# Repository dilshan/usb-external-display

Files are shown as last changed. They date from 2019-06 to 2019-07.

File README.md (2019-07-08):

# USB seven segment display module

USB Display Module

This seven segment display module is specifically designed to work with *POS* systems and banking applications. Initially, this module is developed to work with PC based systems, and later it was modified to work with other platforms and applications.

To simplify the communication interface this unit emulates a *COM* port in the host terminal. Because of this feature, this module can work with many systems without having any additional device driver(s).

This display module is designed around *STM32F103CB* MCU. The firmware of this display unit operates with most of the *STM32F103C* series MCUs, which including *STM32F103C8T6* based Blue Pill board. 

This is [certified](https://certification.oshwa.org/lk000003.html) open source hardware project. All the design files, [documentation](https://github.com/dilshan/usb-external-display/wiki), firmware source code are available to download at the [project source repository](https://github.com/dilshan/usb-external-display/releases). All the content of this project are distributed under the terms of the following license:

-   Hardware License: [CC BY 4.0](https://creativecommons.org/licenses/by/4.0/)
-   Software License: [MIT](https://github.com/dilshan/usb-external-display/blob/master/LICENSE)
-   Documentation License: [CC BY 4.0](https://creativecommons.org/licenses/by/4.0/)

OSHW-LK000003 (https://certification.oshwa.org/lk000003.html)

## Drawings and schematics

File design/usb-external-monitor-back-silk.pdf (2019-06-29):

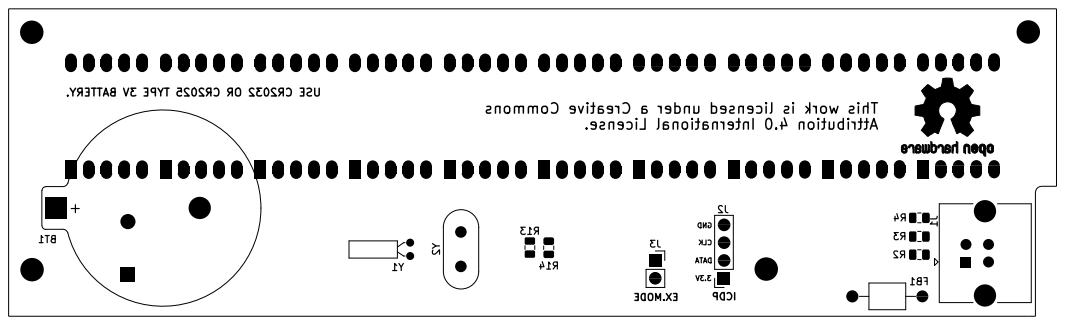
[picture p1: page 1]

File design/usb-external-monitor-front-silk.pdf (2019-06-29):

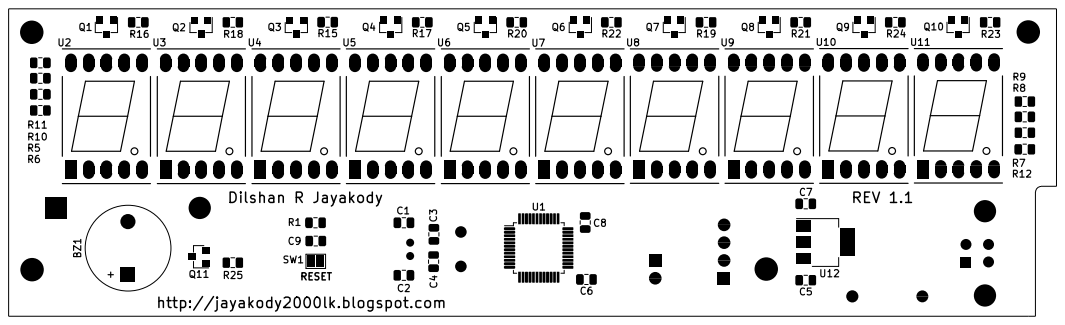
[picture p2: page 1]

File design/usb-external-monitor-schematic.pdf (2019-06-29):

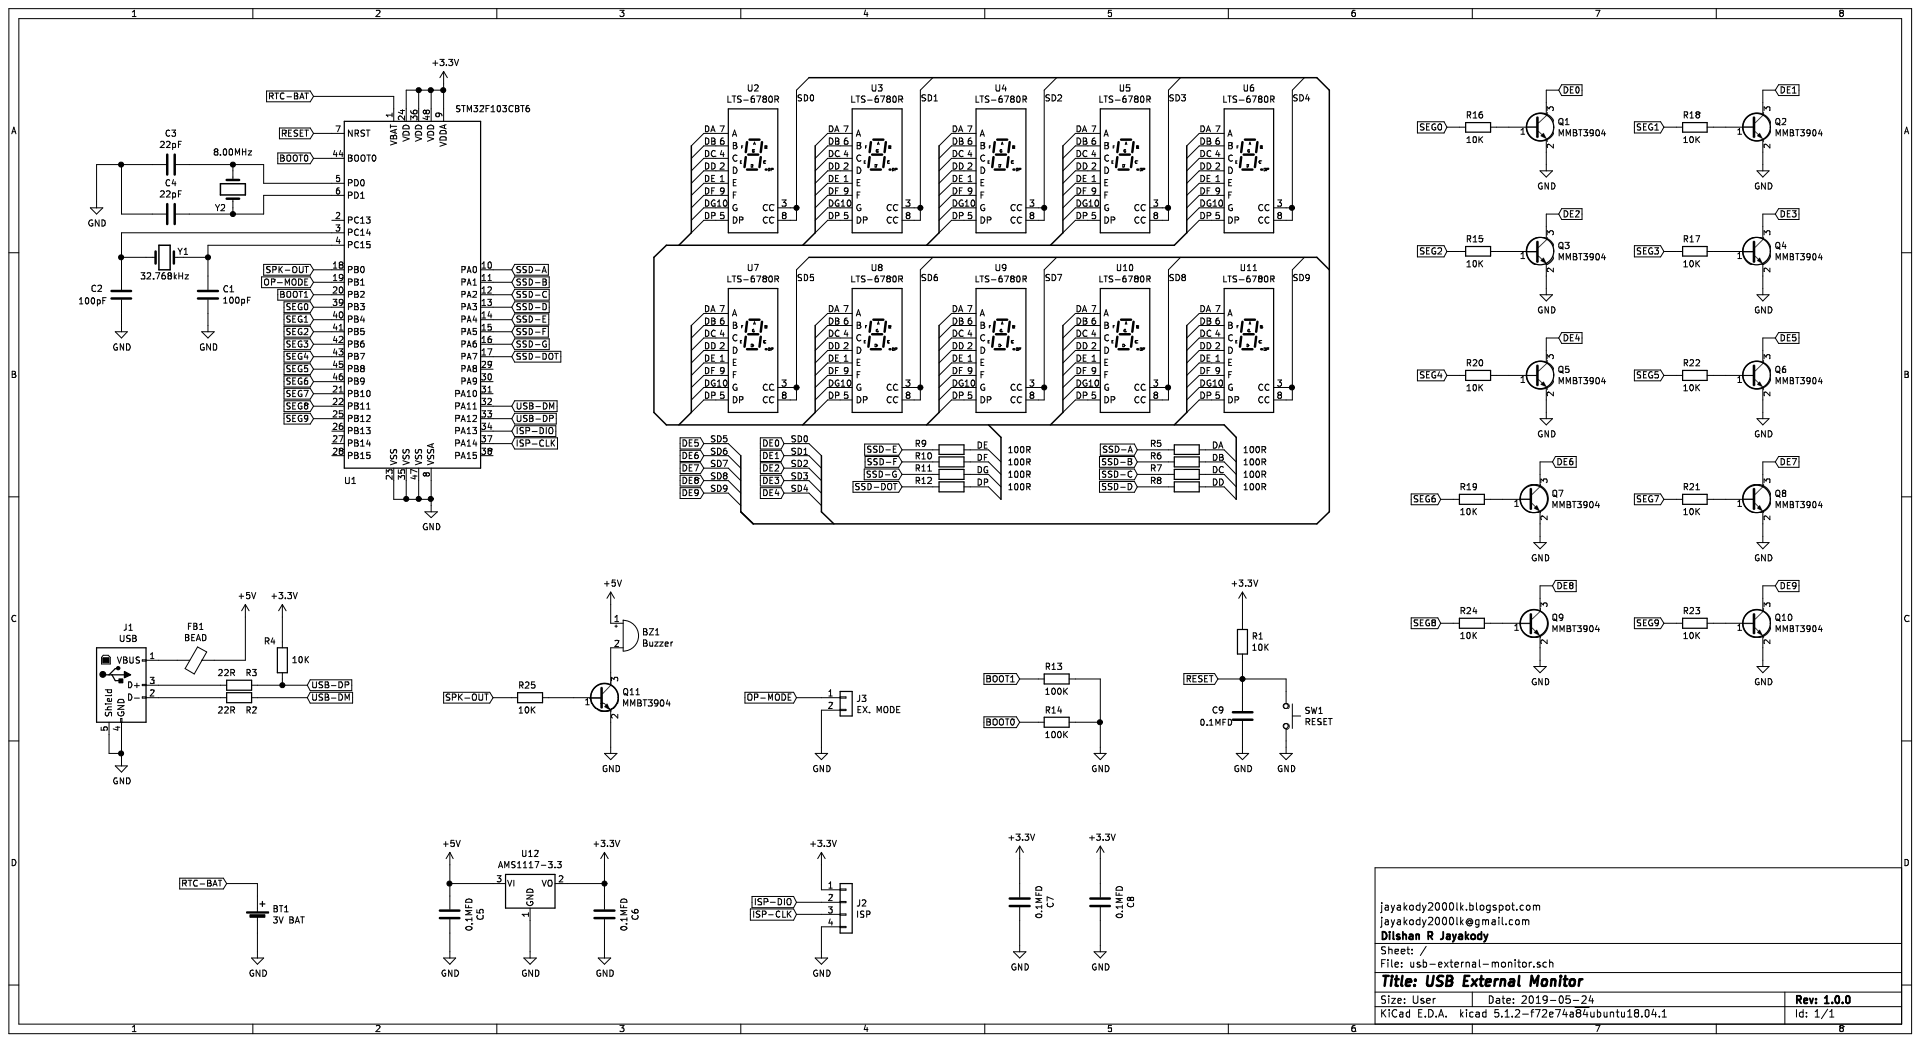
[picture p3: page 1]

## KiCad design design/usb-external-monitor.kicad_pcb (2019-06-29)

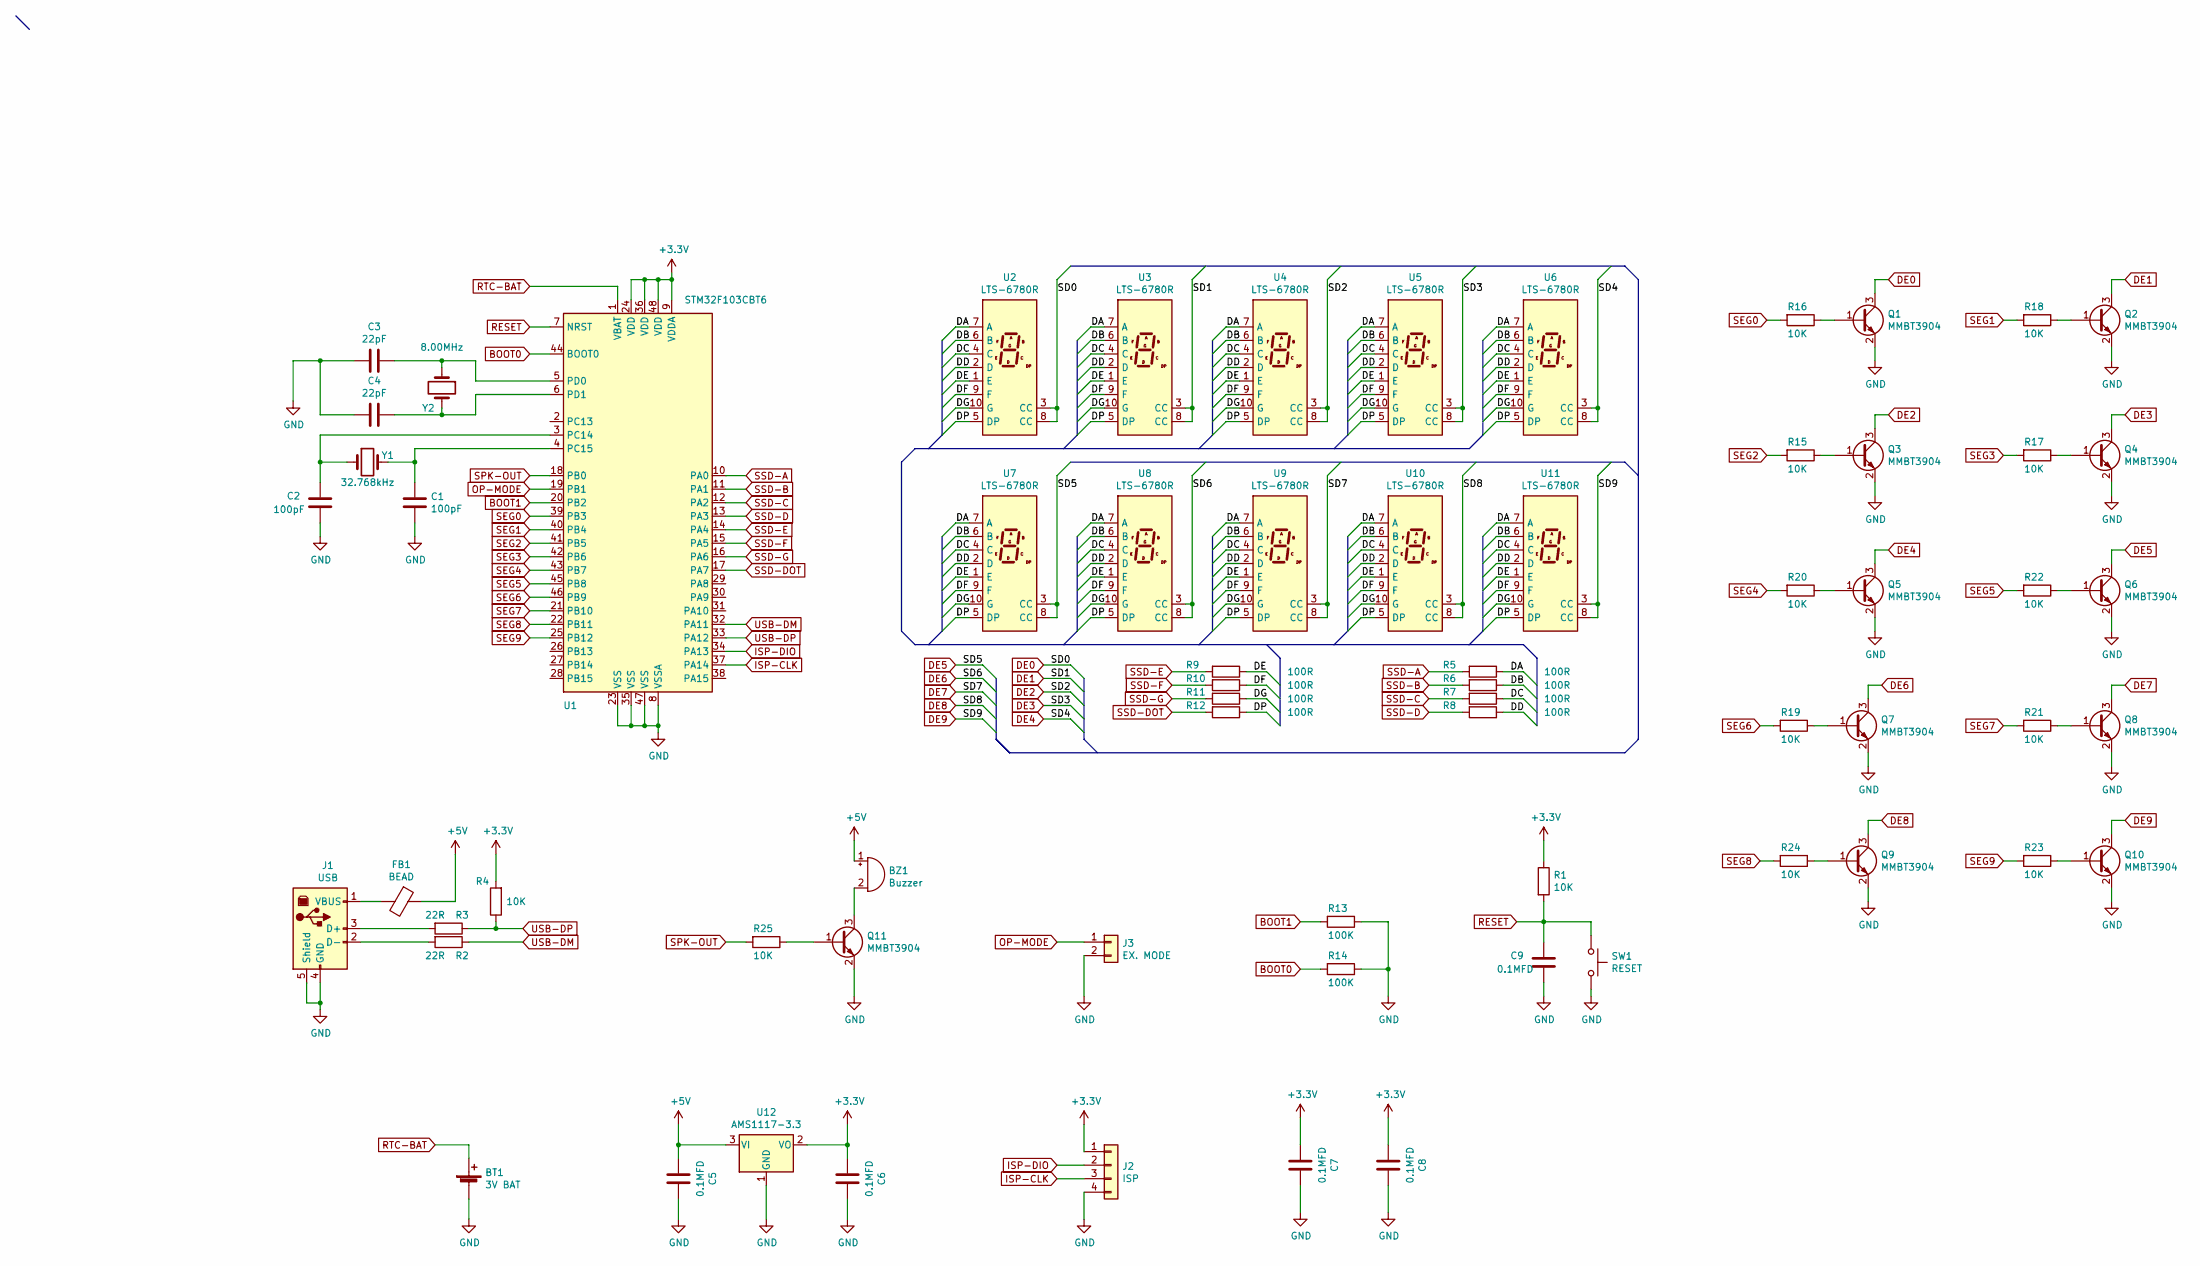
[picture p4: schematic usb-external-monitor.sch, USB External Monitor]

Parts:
BT1: 3V BAT; BatteryHolder_Keystone_105_1x2430
BZ1: Buzzer; Buzzer_12x9.5RM7.6
C1, C2: 100pF; C_0805_2012Metric
C3, C4: 22pF; C_0805_2012Metric
C5, C6, C7, C8, C9: 0.1MFD; C_0805_2012Metric
FB1: BEAD; L_Axial_L5.0mm_D3.6mm_P10.00mm_Horizontal_Murata_BL01RN1A2A2
J1: USB; USB_B_TE_5787834_Vertical
J2: ISP; PinHeader_1x04_P2.54mm_Vertical
J3: EX. MODE; PinHeader_1x02_P2.54mm_Vertical
Q1, Q2, Q3, Q4, Q5, Q6, Q7, Q8, Q9, Q10, Q11: MMBT3904; SOT-23
R1, R4, R15, R16, R17, R18, R19, R20, R21, R22, R23, R24, R25: 10K; R_0805_2012Metric
R2, R3: 22R; R_0805_2012Metric
R5, R6, R7, R8, R9, R10, R11, R12: 100R; R_0805_2012Metric
R13, R14: 100K; R_0805_2012Metric
SW1: RESET; SolderJumper-2_P1.3mm_Open_Pad1.0x1.5mm
U1: STM32F103CBT6; LQFP-48_7x7mm_P0.5mm
U2, U3, U4, U5, U6, U7, U8, U9, U10, U11: LTS-6780R; 7SegmentLED_LTS6760_LTS6780
U12: AMS1117-3.3; SOT-223-3_TabPin2
Y1: 32.768kHz; Crystal_C26-LF_D2.1mm_L6.5mm_Horizontal
Y2: 8.00MHz; Crystal_HC49-U_Vertical

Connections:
+3V3: C6.2, C7.2, C8.2, J2.1, R1.1, R4.2, U1.9 (VDDA), U1.24 (VDD), U1.36 (VDD), U1.48 (VDD), U12.2 (VO)
+5V: BZ1.1 (-), C5.2, FB1.1, U12.3 (VI)
/DA: R5.1, U2.7 (A), U3.7 (A), U4.7 (A), U5.7 (A), U6.7 (A), U7.7 (A), U8.7 (A), U9.7 (A), U10.7 (A), U11.7 (A)
/DB: R6.1, U2.6 (B), U3.6 (B), U4.6 (B), U5.6 (B), U6.6 (B), U7.6 (B), U8.6 (B), U9.6 (B), U10.6 (B), U11.6 (B)
/DC: R7.1, U2.4 (C), U3.4 (C), U4.4 (C), U5.4 (C), U6.4 (C), U7.4 (C), U8.4 (C), U9.4 (C), U10.4 (C), U11.4 (C)
/DD: R8.1, U2.2 (D), U3.2 (D), U4.2 (D), U5.2 (D), U6.2 (D), U7.2 (D), U8.2 (D), U9.2 (D), U10.2 (D), U11.2 (D)
/DE: R9.1, U2.1 (E), U3.1 (E), U4.1 (E), U5.1 (E), U6.1 (E), U7.1 (E), U8.1 (E), U9.1 (E), U10.1 (E), U11.1 (E)
/DF: R10.1, U2.9 (F), U3.9 (F), U4.9 (F), U5.9 (F), U6.9 (F), U7.9 (F), U8.9 (F), U9.9 (F), U10.9 (F), U11.9 (F)
/DG: R11.1, U2.10 (G), U3.10 (G), U4.10 (G), U5.10 (G), U6.10 (G), U7.10 (G), U8.10 (G), U9.10 (G), U10.10 (G), U11.10 (G)
/DP: R12.1, U2.5 (DP), U3.5 (DP), U4.5 (DP), U5.5 (DP), U6.5 (DP), U7.5 (DP), U8.5 (DP), U9.5 (DP), U10.5 (DP), U11.5 (DP)
BOOT0: R14.2, U1.44 (BOOT0)
BOOT1: R13.2, U1.20 (PB2)
DE0: Q1.3 (C), U2.3 (CC), U2.8 (CC)
DE1: Q2.3 (C), U3.3 (CC), U3.8 (CC)
DE2: Q3.3 (C), U4.3 (CC), U4.8 (CC)
DE3: Q4.3 (C), U5.3 (CC), U5.8 (CC)
DE4: Q5.3 (C), U6.3 (CC), U6.8 (CC)
DE5: Q6.3 (C), U7.3 (CC), U7.8 (CC)
DE6: Q7.3 (C), U8.3 (CC), U8.8 (CC)
DE7: Q8.3 (C), U9.3 (CC), U9.8 (CC)
DE8: Q9.3 (C), U10.3 (CC), U10.8 (CC)
DE9: Q10.3 (C), U11.3 (CC), U11.8 (CC)
GND: BT1.2 (-), C1.2, C2.2, C3.2, C4.2, C5.1, C6.1, C7.1, C8.1, C9.2, J1.4 (GND), J1.5 (Shield), J2.4, J3.2, Q1.2 (E), Q2.2 (E), Q3.2 (E), Q4.2 (E), Q5.2 (E), Q6.2 (E), Q7.2 (E), Q8.2 (E), Q9.2 (E), Q10.2 (E), Q11.2 (E), R13.1, R14.1, SW1.2, U1.8 (VSSA), U1.23 (VSS), U1.35 (VSS), U1.47 (VSS), U12.1 (GND)
ISP-CLK: J2.3, U1.37 (PA14)
ISP-DIO: J2.2, U1.34 (PA13)
unnamed: BZ1.2 (+), Q11.3 (C)
unnamed: C1.1, U1.4 (PC15), Y1.2
unnamed: C2.1, U1.3 (PC14), Y1.1
unnamed: C3.1, U1.5 (PD0), Y2.1
unnamed: C4.1, U1.6 (PD1), Y2.2
unnamed: FB1.2, J1.1 (VBUS)
unnamed: J1.2 (D-), R2.2
unnamed: J1.3 (D+), R3.2
unnamed: Q1.1 (B), R16.1
unnamed: Q2.1 (B), R18.1
unnamed: Q3.1 (B), R15.1
unnamed: Q4.1 (B), R17.1
unnamed: Q5.1 (B), R20.1
unnamed: Q6.1 (B), R22.1
unnamed: Q7.1 (B), R19.1
unnamed: Q8.1 (B), R21.1
unnamed: Q9.1 (B), R24.1
unnamed: Q10.1 (B), R23.1
unnamed: Q11.1 (B), R25.1
OP-MODE: J3.1, U1.19 (PB1)
RESET: C9.1, R1.2, SW1.1, U1.7 (NRST)
RTC-BAT: BT1.1 (+), U1.1 (VBAT)
SEG0: R16.2, U1.39 (PB3)
SEG1: R18.2, U1.40 (PB4)
SEG2: R15.2, U1.41 (PB5)
SEG3: R17.2, U1.42 (PB6)
SEG4: R20.2, U1.43 (PB7)
SEG5: R22.2, U1.45 (PB8)
SEG6: R19.2, U1.46 (PB9)
SEG7: R21.2, U1.21 (PB10)
SEG8: R24.2, U1.22 (PB11)
SEG9: R23.2, U1.25 (PB12)
SPK-OUT: R25.2, U1.18 (PB0)
SSD-A: R5.2, U1.10 (PA0)
SSD-B: R6.2, U1.11 (PA1)
SSD-C: R7.2, U1.12 (PA2)
SSD-D: R8.2, U1.13 (PA3)
SSD-DOT: R12.2, U1.17 (PA7)
SSD-E: R9.2, U1.14 (PA4)
SSD-F: R10.2, U1.15 (PA5)
SSD-G: R11.2, U1.16 (PA6)
USB-DM: R2.1, U1.32 (PA11)
USB-DP: R3.1, R4.1, U1.33 (PA12)

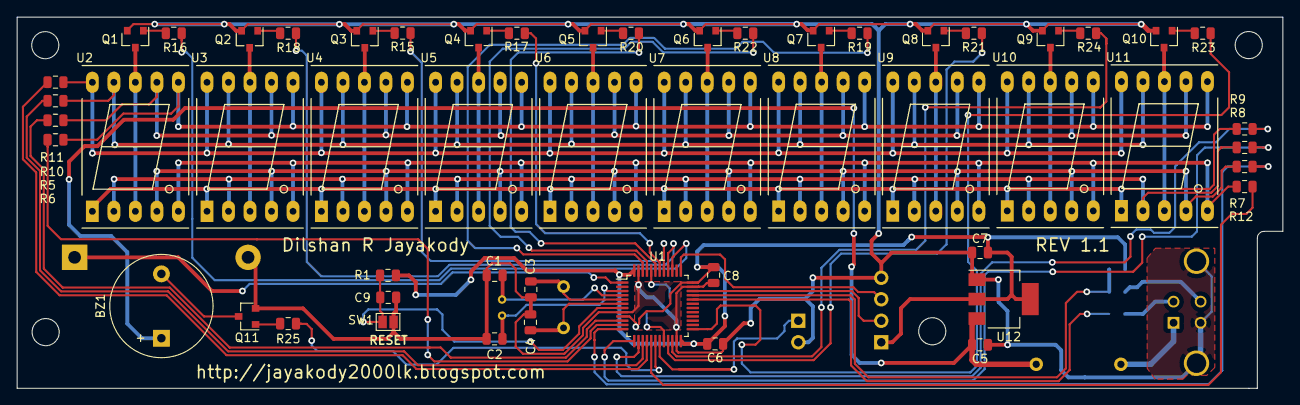
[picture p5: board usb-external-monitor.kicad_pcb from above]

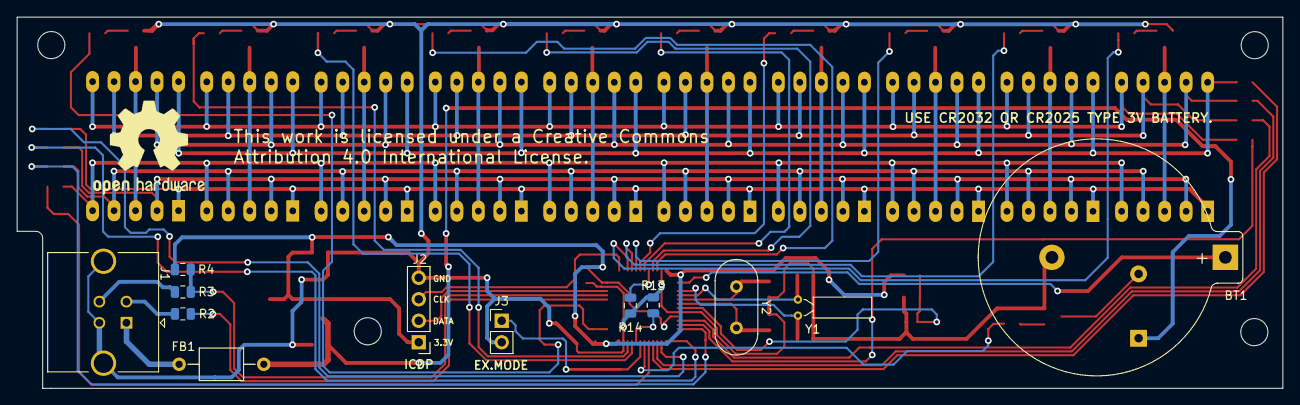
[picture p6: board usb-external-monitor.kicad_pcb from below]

Board: 2 copper layers, 149.5 x 43.8 mm, 70 parts (12 on the bottom side), 68 nets.

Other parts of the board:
 : MountingHole_3.2mm_M3
 #2,  #3,  #4: MountingHole_3.2mm_M3

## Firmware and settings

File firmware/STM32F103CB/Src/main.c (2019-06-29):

/******************************************************************************
 *
 * Part of this software component is licensed by ST under Ultimate Liberty
 * license SLA0044, the "License"; You may not use this file except in
 * compliance with the License. You may obtain a copy of the License at:
 *                             www.st.com/SLA0044
 *
 *****************************************************************************/

#include "main.h"
#include "usb_device.h"

#include "display_manager.h"
#include "counter_controller.h"
#include "storage_manager.h"

TIM_HandleTypeDef htim2;
TIM_HandleTypeDef htim3;

uint8_t bellCounter;
uint8_t rtcRefreshCounter;
ExtIdleMode currentIdleMode;

void initSystemClockConfig(void);
static void initRTCConfig(void);
static void initPortConfig(void);

static void initTimer2Config(void);
static void initTimer3Config(void);
static void initTimer4Config(void);

int main(void)
{
	HAL_Init();

	currentState = ECNT_IDLE_MODE;
	currentIdleMode = IDLE_TIME;
	systemMode = OP_EXTEND;
	bellState = BELL_OFF;

	lastSystemState = currentState;
	idleCounter = 0;
	bellCounter = 0;

	initSystemClockConfig();

	// Initialize system peripherals.
	initPortConfig();
	initTimer2Config();
	initTimer3Config();
	initTimer4Config();
	MX_USB_DEVICE_Init();
	initRTCConfig();

	rtcRefreshCounter = 0;

	// Initialize seven segment display system.
	initDisplaySystem();

	// Start timer 2 to update the SSD with display buffer.
	HAL_TIM_Base_Start_IT(&htim2);

	// Load saved system settings from flash memory.
	if(getBuffer() != HAL_OK)
	{
	  Error_Handler();
	}

	// At initial boot up system should be in idle state.
	updateIdleDisaplay();

	while (1)
	{
		systemMode = (HAL_GPIO_ReadPin(OP_MODE_GPIO_Port, OP_MODE_Pin) == GPIO_PIN_SET) ? OP_EXTEND : OP_DIRECT;

		if((currentState == ECNT_TIME_MODE) || (currentState == ECNT_IDLE_MODE))
		{
			currentIdleMode = getIdleModeConfig();

			if((currentState == ECNT_IDLE_MODE) && ((currentIdleMode == IDLE_CUSTOM) || (currentIdleMode == IDLE_NONE)))
			{
				HAL_Delay(100);
				continue;
			}

			// Update date and time variables in every 1 second
			if((++rtcRefreshCounter) == 10)
			{
				updateIdleDisaplay();
				rtcRefreshCounter = 0;
			}
		}

		// Check audio state and control audio out pin.
		if(bellState != BELL_OFF)
		{
			if(bellState == BELL_START)
			{
				// Activate audio buzzer.
				bellState = BELL_STOP;
				bellCounter = 0;
				HAL_TIM_PWM_Start(&htim3, TIM_CHANNEL_3);
			}
			else if((bellState == BELL_STOP) && (bellCounter > 3))
			{
				// Deactivate audio buzzer.
				bellState = BELL_OFF;
				HAL_TIM_PWM_Stop(&htim3, TIM_CHANNEL_3);
			}

			bellCounter++;
		}

		HAL_Delay(100);
	}
}

void initSystemClockConfig(void)
{
	RCC_OscInitTypeDef sOscConfig = {0};
	RCC_ClkInitTypeDef sClockConfig = {0};
	RCC_PeriphCLKInitTypeDef sPeriphConfig = {0};

	// Initializes the CPU, AHB and APB busses clocks.

#ifdef ENABLE_EXTERNAL_RTC_CRYSTAL
	sOscConfig.OscillatorType = RCC_OSCILLATORTYPE_HSE|RCC_OSCILLATORTYPE_LSE;
	sOscConfig.LSEState = RCC_LSE_ON;
#else
	sOscConfig.OscillatorType = RCC_OSCILLATORTYPE_HSE;
#endif

	sOscConfig.HSEState = RCC_HSE_ON;
	sOscConfig.HSEPredivValue = RCC_HSE_PREDIV_DIV1;
	sOscConfig.HSIState = RCC_HSI_ON;
	sOscConfig.PLL.PLLState = RCC_PLL_ON;
	sOscConfig.PLL.PLLSource = RCC_PLLSOURCE_HSE;
	sOscConfig.PLL.PLLMUL = RCC_PLL_MUL6;

	if (HAL_RCC_OscConfig(&sOscConfig) != HAL_OK)
	{
		Error_Handler();
	}

	sClockConfig.ClockType = RCC_CLOCKTYPE_HCLK|RCC_CLOCKTYPE_SYSCLK |RCC_CLOCKTYPE_PCLK1|RCC_CLOCKTYPE_PCLK2;
	sClockConfig.SYSCLKSource = RCC_SYSCLKSOURCE_PLLCLK;
	sClockConfig.AHBCLKDivider = RCC_SYSCLK_DIV1;
	sClockConfig.APB1CLKDivider = RCC_HCLK_DIV2;
	sClockConfig.APB2CLKDivider = RCC_HCLK_DIV1;

	if (HAL_RCC_ClockConfig(&sClockConfig, FLASH_LATENCY_1) != HAL_OK)
	{
		Error_Handler();
	}

	sPeriphConfig.PeriphClockSelection = RCC_PERIPHCLK_RTC|RCC_PERIPHCLK_USB;

#ifdef ENABLE_EXTERNAL_RTC_CRYSTAL
	sPeriphConfig.RTCClockSelection = RCC_RTCCLKSOURCE_LSE;
#else
	sPeriphConfig.RTCClockSelection = RCC_RTCCLKSOURCE_HSE_DIV128;
#endif

	sPeriphConfig.UsbClockSelection = RCC_USBCLKSOURCE_PLL;

	if (HAL_RCCEx_PeriphCLKConfig(&sPeriphConfig) != HAL_OK)
	{
		Error_Handler();
	}
}

static void initRTCConfig(void)
{
	RTC_TimeTypeDef sTime = {0};
	RTC_DateTypeDef sDate = {0};

	// Initialize RTC Only.
	hrtc.Instance = RTC;
	hrtc.Init.AsynchPrediv = RTC_AUTO_1_SECOND;
	hrtc.Init.OutPut = RTC_OUTPUTSOURCE_NONE;

	if (HAL_RTC_Init(&hrtc) != HAL_OK)
	{
		Error_Handler();
	}

	// Return if RTC is already setup in previous instance.
	if(HAL_RTCEx_BKUPRead(&hrtc, RTC_BKP_DR1) == RTC_BACKUP_FLAG)
	{
		return;
	}

	// Initialize RTC and set the Time and Date.
	sTime.Hours = 0x0;
	sTime.Minutes = 0x0;
	sTime.Seconds = 0x0;

	if (HAL_RTC_SetTime(&hrtc, &sTime, RTC_FORMAT_BCD) != HAL_OK)
	{
		Error_Handler();
	}

	sDate.WeekDay = RTC_WEEKDAY_MONDAY;
	sDate.Month = RTC_MONTH_JANUARY;
	sDate.Date = 0x1;
	sDate.Year = 0x0;

	if (HAL_RTC_SetDate(&hrtc, &sDate, RTC_FORMAT_BCD) != HAL_OK)
	{
		Error_Handler();
	}

	// Setup flag in backup register to avoid RTC resets.
	HAL_RTCEx_BKUPWrite(&hrtc, RTC_BKP_DR1, RTC_BACKUP_FLAG);
}

static void initTimer2Config(void)
{
	TIM_ClockConfigTypeDef sClockSourceConfig = {0};
	TIM_MasterConfigTypeDef sMasterConfig = {0};

	htim2.Instance = TIM2;
	htim2.Init.Prescaler = 5;
	htim2.Init.CounterMode = TIM_COUNTERMODE_UP;
	htim2.Init.Period = 59999;
	htim2.Init.ClockDivision = TIM_CLOCKDIVISION_DIV1;
	htim2.Init.AutoReloadPreload = TIM_AUTORELOAD_PRELOAD_DISABLE;

	if (HAL_TIM_Base_Init(&htim2) != HAL_OK)
	{
		Error_Handler();
	}

	sClockSourceConfig.ClockSource = TIM_CLOCKSOURCE_INTERNAL;

	if (HAL_TIM_ConfigClockSource(&htim2, &sClockSourceConfig) != HAL_OK)
	{
		Error_Handler();
	}

	sMasterConfig.MasterOutputTrigger = TIM_TRGO_RESET;
	sMasterConfig.MasterSlaveMode = TIM_MASTERSLAVEMODE_DISABLE;

	if (HAL_TIMEx_MasterConfigSynchronization(&htim2, &sMasterConfig) != HAL_OK)
	{
		Error_Handler();
	}
}

static void initTimer3Config(void)
{
	TIM_ClockConfigTypeDef sClockSourceConfig = {0};
	TIM_MasterConfigTypeDef sMasterConfig = {0};
	TIM_OC_InitTypeDef sConfigOC = {0};

	htim3.Instance = TIM3;
	htim3.Init.Prescaler = 10;
	htim3.Init.CounterMode = TIM_COUNTERMODE_UP;
	htim3.Init.Period = 9696;
	htim3.Init.ClockDivision = TIM_CLOCKDIVISION_DIV1;
	htim3.Init.AutoReloadPreload = TIM_AUTORELOAD_PRELOAD_DISABLE;

	if (HAL_TIM_Base_Init(&htim3) != HAL_OK)
	{
		Error_Handler();
	}
	sClockSourceConfig.ClockSource = TIM_CLOCKSOURCE_INTERNAL;

	if (HAL_TIM_ConfigClockSource(&htim3, &sClockSourceConfig) != HAL_OK)
	{
		Error_Handler();
	}

	if (HAL_TIM_PWM_Init(&htim3) != HAL_OK)
	{
		Error_Handler();
	}

	sMasterConfig.MasterOutputTrigger = TIM_TRGO_RESET;
	sMasterConfig.MasterSlaveMode = TIM_MASTERSLAVEMODE_DISABLE;

	if (HAL_TIMEx_MasterConfigSynchronization(&htim3, &sMasterConfig) != HAL_OK)
	{
		Error_Handler();
	}

	// Initialize PWM on channel 3 using timer3.
	sConfigOC.OCMode = TIM_OCMODE_PWM1;
	sConfigOC.Pulse = 29000;
	sConfigOC.OCPolarity = TIM_OCPOLARITY_HIGH;
	sConfigOC.OCFastMode = TIM_OCFAST_DISABLE;

	if (HAL_TIM_PWM_ConfigChannel(&htim3, &sConfigOC, TIM_CHANNEL_3) != HAL_OK)
	{
		Error_Handler();
	}

	HAL_TIM_MspPostInit(&htim3);
}

static void initTimer4Config(void)
{
	TIM_ClockConfigTypeDef sClockSourceConfig = {0};
	TIM_MasterConfigTypeDef sMasterConfig = {0};

	htim4.Instance = TIM4;
	htim4.Init.Prescaler = 749;
	htim4.Init.CounterMode = TIM_COUNTERMODE_UP;
	htim4.Init.Period = 63999;
	htim4.Init.ClockDivision = TIM_CLOCKDIVISION_DIV1;
	htim4.Init.AutoReloadPreload = TIM_AUTORELOAD_PRELOAD_DISABLE;

	if (HAL_TIM_Base_Init(&htim4) != HAL_OK)
	{
		Error_Handler();
	}

	sClockSourceConfig.ClockSource = TIM_CLOCKSOURCE_INTERNAL;

	if (HAL_TIM_ConfigClockSource(&htim4, &sClockSourceConfig) != HAL_OK)
	{
		Error_Handler();
	}

	sMasterConfig.MasterOutputTrigger = TIM_TRGO_RESET;
	sMasterConfig.MasterSlaveMode = TIM_MASTERSLAVEMODE_DISABLE;

	if (HAL_TIMEx_MasterConfigSynchronization(&htim4, &sMasterConfig) != HAL_OK)
	{
		Error_Handler();
	}
}

static void initPortConfig(void)
{
	GPIO_InitTypeDef sGPIOConfig = {0};

	__HAL_RCC_GPIOC_CLK_ENABLE();
	__HAL_RCC_GPIOD_CLK_ENABLE();
	__HAL_RCC_GPIOA_CLK_ENABLE();
	__HAL_RCC_GPIOB_CLK_ENABLE();

	// Configure GPIOA.
	HAL_GPIO_WritePin(GPIOA, SSD_A_Pin|SSD_B_Pin|SSD_C_Pin|SSD_D_Pin |SSD_E_Pin|SSD_F_Pin|SSD_G_Pin|SSD_DOT_Pin, GPIO_PIN_RESET);

	// Configure GPIOB.
	HAL_GPIO_WritePin(GPIOB, SSD_8_Pin|SSD_9_Pin|SSD_10_Pin|SSD_1_Pin |SSD_2_Pin|SSD_3_Pin|SSD_4_Pin|SSD_5_Pin |SSD_6_Pin|SSD_7_Pin, GPIO_PIN_RESET);

	sGPIOConfig.Pin = SSD_A_Pin|SSD_B_Pin|SSD_C_Pin|SSD_D_Pin |SSD_E_Pin|SSD_F_Pin|SSD_G_Pin|SSD_DOT_Pin;

	sGPIOConfig.Mode = GPIO_MODE_OUTPUT_PP;
	sGPIOConfig.Pull = GPIO_NOPULL;
	sGPIOConfig.Speed = GPIO_SPEED_FREQ_LOW;
	HAL_GPIO_Init(GPIOA, &sGPIOConfig);

	sGPIOConfig.Pin = OP_MODE_Pin;
	sGPIOConfig.Mode = GPIO_MODE_INPUT;
	sGPIOConfig.Pull = GPIO_PULLUP;
	HAL_GPIO_Init(OP_MODE_GPIO_Port, &sGPIOConfig);

	sGPIOConfig.Pin = SSD_8_Pin|SSD_9_Pin|SSD_10_Pin|SSD_1_Pin |SSD_2_Pin|SSD_3_Pin|SSD_4_Pin|SSD_5_Pin |SSD_6_Pin|SSD_7_Pin;
	sGPIOConfig.Mode = GPIO_MODE_OUTPUT_PP;
	sGPIOConfig.Pull = GPIO_NOPULL;
	sGPIOConfig.Speed = GPIO_SPEED_FREQ_LOW;
	HAL_GPIO_Init(GPIOB, &sGPIOConfig);
}

void Error_Handler(void)
{}

#ifdef  USE_FULL_ASSERT
void assert_failed(uint8_t *file, uint32_t line)
{}
#endif

/************************ (C) COPYRIGHT STMicroelectronics *****END OF FILE****/

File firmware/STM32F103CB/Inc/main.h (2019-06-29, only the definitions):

#define RTC_BACKUP_FLAG 102
#define SSD_A_Pin GPIO_PIN_0
#define SSD_A_GPIO_Port GPIOA
#define SSD_B_Pin GPIO_PIN_1
#define SSD_B_GPIO_Port GPIOA
#define SSD_C_Pin GPIO_PIN_2
#define SSD_C_GPIO_Port GPIOA
#define SSD_D_Pin GPIO_PIN_3
#define SSD_D_GPIO_Port GPIOA
#define SSD_E_Pin GPIO_PIN_4
#define SSD_E_GPIO_Port GPIOA
#define SSD_F_Pin GPIO_PIN_5
#define SSD_F_GPIO_Port GPIOA
#define SSD_G_Pin GPIO_PIN_6
#define SSD_G_GPIO_Port GPIOA
#define SSD_DOT_Pin GPIO_PIN_7
#define SSD_DOT_GPIO_Port GPIOA
#define SPK_OUT_Pin GPIO_PIN_0
#define SPK_OUT_GPIO_Port GPIOB
#define OP_MODE_Pin GPIO_PIN_1
#define OP_MODE_GPIO_Port GPIOB
#define SSD_8_Pin GPIO_PIN_10
#define SSD_8_GPIO_Port GPIOB
#define SSD_9_Pin GPIO_PIN_11
#define SSD_9_GPIO_Port GPIOB
#define SSD_10_Pin GPIO_PIN_12
#define SSD_10_GPIO_Port GPIOB
#define SSD_1_Pin GPIO_PIN_3
#define SSD_1_GPIO_Port GPIOB
#define SSD_2_Pin GPIO_PIN_4
#define SSD_2_GPIO_Port GPIOB
#define SSD_3_Pin GPIO_PIN_5
#define SSD_3_GPIO_Port GPIOB
#define SSD_4_Pin GPIO_PIN_6
#define SSD_4_GPIO_Port GPIOB
#define SSD_5_Pin GPIO_PIN_7
#define SSD_5_GPIO_Port GPIOB
#define SSD_6_Pin GPIO_PIN_8
#define SSD_6_GPIO_Port GPIOB
#define SSD_7_Pin GPIO_PIN_9
#define SSD_7_GPIO_Port GPIOB

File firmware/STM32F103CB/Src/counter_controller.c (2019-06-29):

/******************************************************************************
 * Copyright 2019 Dilshan R Jayakody. [jayakody2000lk@gmail.com]
 *
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
 * THE SOFTWARE IS PROVIDED "AS IS", WITHOUT WARRANTY OF ANY KIND, EXPRESS OR
 * IMPLIED, INCLUDING BUT NOT LIMITED TO THE WARRANTIES OF MERCHANTABILITY,
 * FITNESS FOR A PARTICULAR PURPOSE AND NONINFRINGEMENT. IN NO EVENT SHALL THE
 * AUTHORS OR COPYRIGHT HOLDERS BE LIABLE FOR ANY CLAIM, DAMAGES OR OTHER
 * LIABILITY, WHETHER IN AN ACTION OF CONTRACT, TORT OR OTHERWISE, ARISING
 * FROM, OUT OF OR IN CONNECTION WITH THE SOFTWARE OR THE USE OR OTHER
 * DEALINGS IN THE SOFTWARE.
 ******************************************************************************/

#include <string.h>

#include "counter_controller.h"
#include "display_manager.h"
#include "storage_manager.h"
#include "global-def.h"

HAL_StatusTypeDef processText(char* Buf, uint32_t* Len)
{
	uint32_t dataLen = *Len;
	int32_t dataPos = (dataLen - 1);

	if(dataLen > 0)
	{
		if(currentState == ECNT_IDLE_MODE)
		{
			setSystemIdleState(EOP_NORMAL);
			currentState = ECNT_MSG_MODE;

			clearDisplay();
		}

		while(dataPos >= 0)
		{
			pushCharToDisplayBuffer(Buf[dataPos]);
			dataPos--;
		}
	}

	return HAL_OK;
}

HAL_StatusTypeDef processCommand(char* Buf, uint32_t* Len)
{
	// Check for valid command length and header.
	uint32_t dataLen = *Len;

	if((dataLen > 1) && (Buf[0] == 94))
	{
		if(Buf[1] == '0')
		{
			// Clear display unit.
			setSystemIdleState(EOP_NORMAL);

			currentState = ECNT_MSG_MODE;

			clearDisplay();
			return HAL_OK;
		}
		else if((Buf[1] == '1') && (dataLen > 2))
		{
			// Display content on the screen.
			uint32_t dataBufferLen = dataLen - 2;
			char tempData[dataBufferLen];

			setSystemIdleState(EOP_NORMAL);

			currentState = ECNT_MSG_MODE;

			memcpy(tempData, (Buf + 2), dataBufferLen);
			setDisplayBuffer(tempData, dataBufferLen);

			return HAL_OK;
		}
		else if((Buf[1] == '2') && (dataLen == 5))
		{
			// Set time of the unit.
			RTC_TimeTypeDef sTime = {0};

			if((Buf[2] < 0) || (Buf[3] < 0) || (Buf[4] < 0))
			{
				return HAL_ERROR;
			}

			if((Buf[2] > 23) || (Buf[3] > 59) || (Buf[4] > 59))
			{
				return HAL_ERROR;
			}

			sTime.Hours = Buf[2];
			sTime.Minutes = Buf[3];
			sTime.Seconds = Buf[4];

			return HAL_RTC_SetTime(&hrtc, &sTime, RTC_FORMAT_BIN);
		}

#ifdef ENABLE_RTC_DATE
		else if((Buf[1] == '3') && (dataLen == 5))
		{
			// Set date of the unit.
			RTC_DateTypeDef sDate = {0};

			if((Buf[2] < 1) || (Buf[3] < 1) || (Buf[4] < 1))
			{
				return HAL_ERROR;
			}

			if((Buf[2] > 31) || (Buf[3] > 12) || (Buf[4] > 99))
			{
				return HAL_ERROR;
			}

			sDate.Date = Buf[2];
			sDate.Month = Buf[3];
			sDate.Year = Buf[4];

			return HAL_RTC_SetDate(&hrtc, &sDate, RTC_FORMAT_BIN);
		}
#endif

		else if(Buf[1] == '4')
		{
			// Switch device into idle mode.
			setSystemIdleState(EOP_IDLE);
			return HAL_OK;
		}
		else if((Buf[1] == '5') && (dataLen > 2))
		{
			// Set custom idle message.
			uint32_t dataBufferLen = dataLen - 2;
			char tempData[MSG_SIZE];

			memset(tempData, DISPLAY_CLEAR, MSG_SIZE);

			memcpy(tempData, (Buf + 2), dataBufferLen);
			setCustomMsg(tempData);

			return HAL_OK;
		}
		else if((Buf[1] == '6') && (dataLen == 3))
		{
			// Set idle mode configuration.
			if(Buf[2] < 4)
			{
				setIdleModeConfig(Buf[2]);
				if(currentState == ECNT_IDLE_MODE)
				{
					updateIdleDisaplay();
				}
				return HAL_OK;
			}
		}
		else if(Buf[1] == '7')
		{
			// Trigger system bell.
			if(currentState != ECNT_IDLE_MODE)
			{
				bellState = BELL_START;
			}
		}
	}

	return HAL_ERROR;
}

void showSystemTime()
{
	const char *outputTemplate;
	char dateOutput[DISPLAY_BUFFER_SIZE];
	RTC_TimeTypeDef sTime = {0};

	memset(dateOutput, (int)NULL, DISPLAY_BUFFER_SIZE);

	if(HAL_RTC_GetTime(&hrtc, &sTime, RTC_FORMAT_BIN) == HAL_OK)
	{
		outputTemplate = ((sTime.Seconds % 2) == 0) ? "   %02d.%02d   " : "   %02d%02d   ";
		sprintf(dateOutput, outputTemplate, sTime.Hours, sTime.Minutes);
		setDisplayBuffer(dateOutput, DISPLAY_BUFFER_SIZE);
	}
}

#ifdef ENABLE_RTC_DATE
void showSystemDate()
{
	char dateOutput[DISPLAY_BUFFER_SIZE];
	RTC_DateTypeDef sDate = {0};

	memset(dateOutput, (int)NULL, DISPLAY_BUFFER_SIZE);

	if(HAL_RTC_GetDate(&hrtc, &sDate, RTC_FORMAT_BIN) == HAL_OK)
	{
		sprintf(dateOutput, "%02d %02d %04d", sDate.Date, sDate.Month, (sDate.Year + 2000));
		setDisplayBuffer(dateOutput, DISPLAY_BUFFER_SIZE);
	}
}
#endif

void showCustomIdleMsg()
{
	char msgBuffer[DISPLAY_BUFFER_SIZE];

	getCustomMsg(msgBuffer);
	setDisplayBuffer(msgBuffer, DISPLAY_BUFFER_SIZE);
}

void setSystemIdleState(ExtCounterIdle idleState)
{
	if(idleState == EOP_IDLE)
	{
		if(currentState != ECNT_IDLE_MODE)
		{
			// System is switching to idle mode.
			HAL_TIM_Base_Stop_IT(&htim4);

			lastSystemState = currentState;
			currentState = ECNT_IDLE_MODE;

			displayDelay = DISPLAY_LOW_POWER;
			updateIdleDisaplay();
		}
	}
	else if(currentState == ECNT_IDLE_MODE)
	{
		// System is recovering from idle mode.
		currentState = lastSystemState;

		displayDelay = DISPLAY_HIGH_POWER;

		idleCounter = 0;
		HAL_TIM_Base_Start_IT(&htim4);
	}
}

void updateIdleDisaplay()
{
	switch(getIdleModeConfig())
	{
		case IDLE_CUSTOM:
			// Show user defined message in idle mode.
			showCustomIdleMsg();
			break;
		case IDLE_TIME:
			// Show system time in idle mode.
			showSystemTime();
			break;
#ifdef ENABLE_RTC_DATE
		case IDLE_DATE:
			// Show system date in idle mode.
			showSystemDate();
			break;
#endif
		case IDLE_NONE:
			// Clear display in idle mode.
			clearDisplay();
			break;
		default:
			showSystemTime();
	}
}

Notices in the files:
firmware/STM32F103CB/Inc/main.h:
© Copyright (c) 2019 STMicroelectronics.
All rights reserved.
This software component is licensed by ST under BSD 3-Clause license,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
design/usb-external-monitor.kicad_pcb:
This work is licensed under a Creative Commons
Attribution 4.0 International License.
